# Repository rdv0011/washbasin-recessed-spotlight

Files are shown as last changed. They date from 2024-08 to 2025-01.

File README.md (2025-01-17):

# Instructions on how to replace a halogen lamp with an LED lamp in a recessed spotlight in a bathroom.

## The following parts need to be purchased

[LED 12V power supply example](https://www.wish.com/product/5b739aba85276f4d7be6cf43).

Any 12V DC power supply with a current of at least 250mA will do. The height of the power supply must accommodate the limited space inside the washbasin furniture.

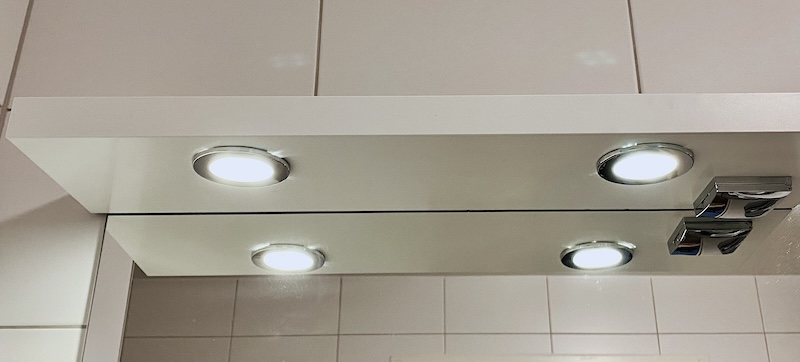
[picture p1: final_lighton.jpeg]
Final light on

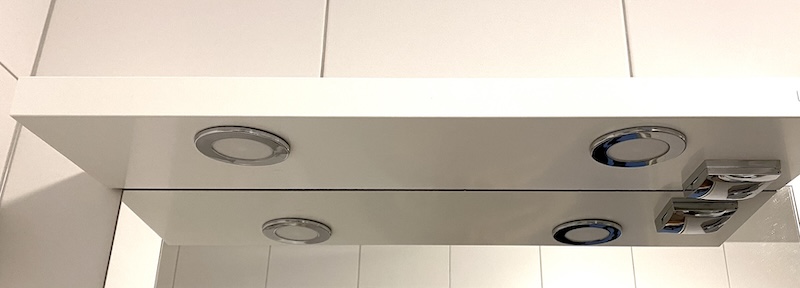
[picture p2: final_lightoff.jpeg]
Final light off


[Aluminum radiator 100x25](https://www.wish.com/search/aluminum%20radiator/product/5ae2c8115194c93728249dd5?source=search&position=48)

[3W Warm white LED](https://www.wish.com/search/LED%203W/product/5957245b2038c73845957045?source=search&position=8)
It is better to use 3W not 1W LED chip. The 3W LED has 2.9V drop wich for 4 LEDs gives 11.6V. This power supply output is 12.12v. The difference is 12.12 - 11.6 = 0.52V. If we want current to be 0.125A then resistor nominal is 0.52V / 0.125A = approx. 4 Ohm. With the current 0.125A four LEDs do not heat up more than 60C. The current limiting resistor dissipates 0.065W.

All necessary parts

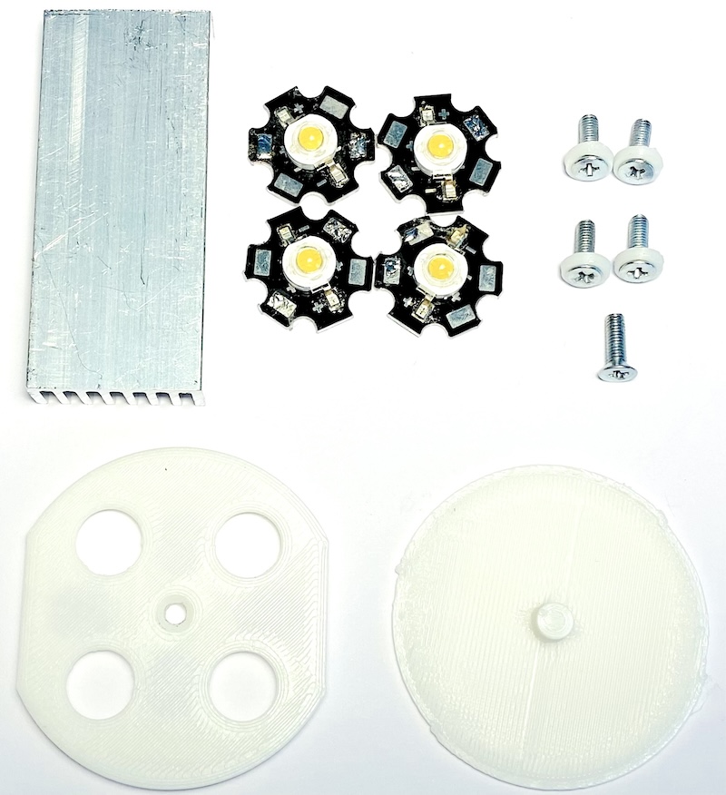
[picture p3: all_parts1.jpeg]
All parts


A wire with a 4 ohm resistor to connect to a 12V DC power supply.

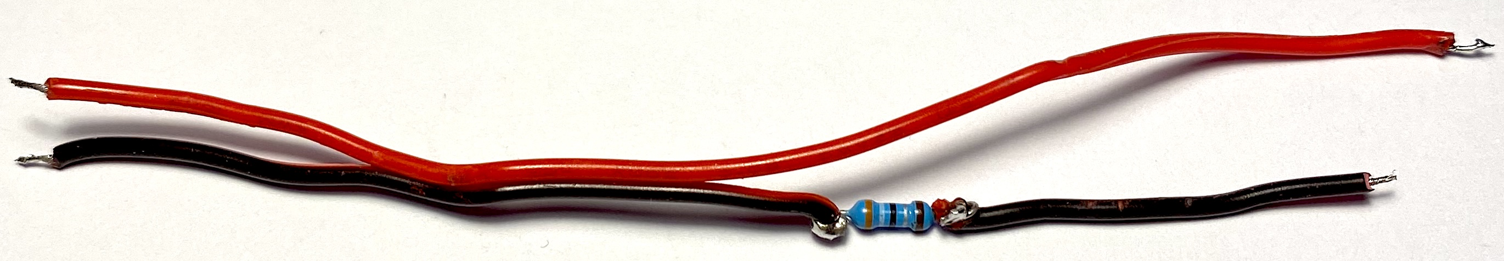
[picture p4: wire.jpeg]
Wire

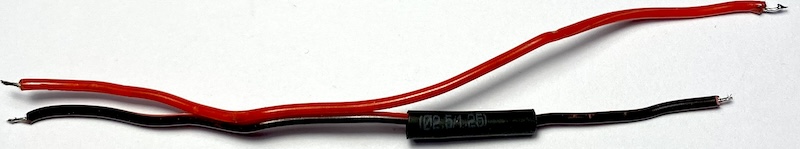
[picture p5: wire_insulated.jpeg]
Wire insulated


Take an aluminum radiator that is 25mm wide, 10mm high and 40mm long or more.

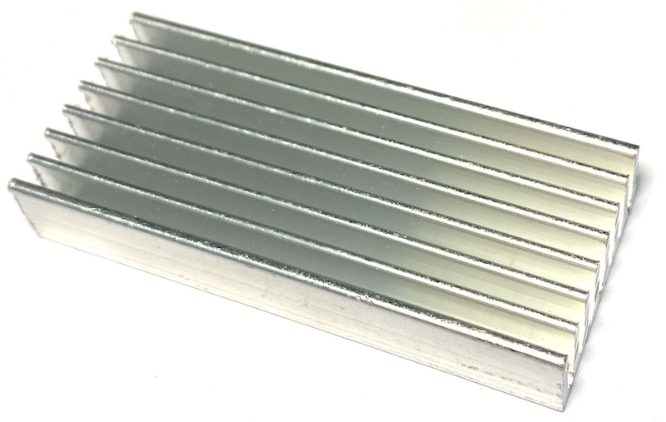
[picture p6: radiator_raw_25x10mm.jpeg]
Raw radiator


Print out the radiator template. To maintain the correct size, use a 103% scaling factor if required by your printer.

Radiator template

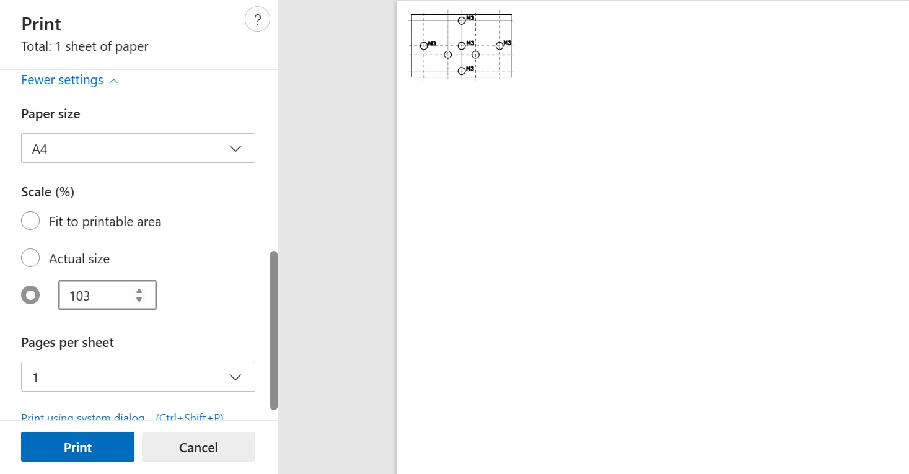
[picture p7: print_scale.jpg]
Print scale


Glue the template to the radiator blank and cut according to the template.

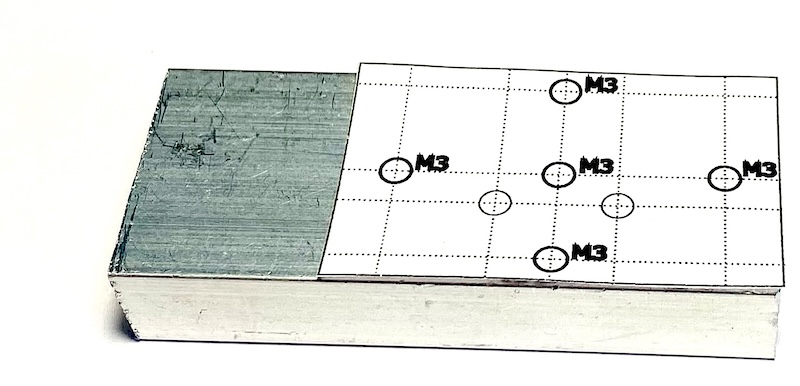
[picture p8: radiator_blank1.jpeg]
Template on radiator


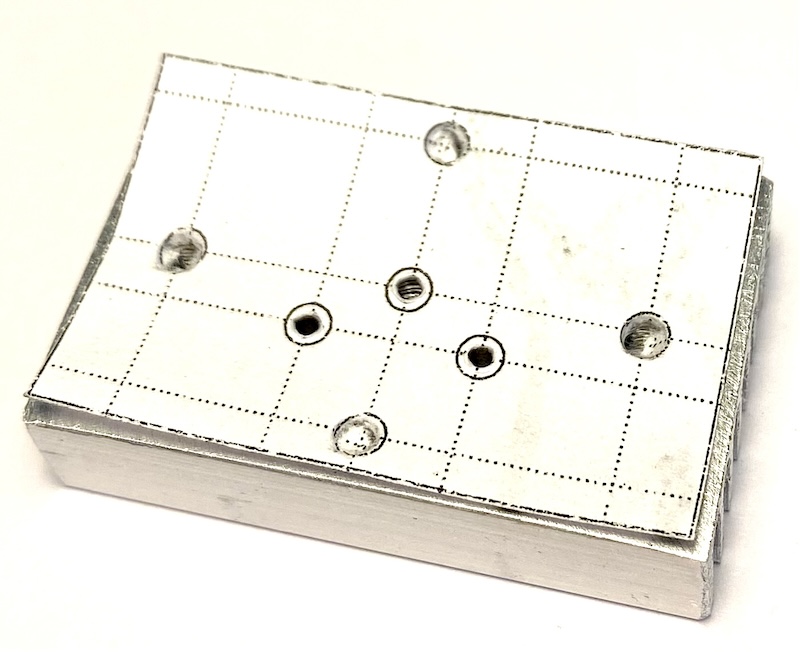
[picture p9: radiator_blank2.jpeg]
Template on radiator


Drill holes with a 2.5 mm drill marked M3. After this, make an M3 thread in the holes marked M3. Drill the remaining two holes with a diameter of 3 mm.

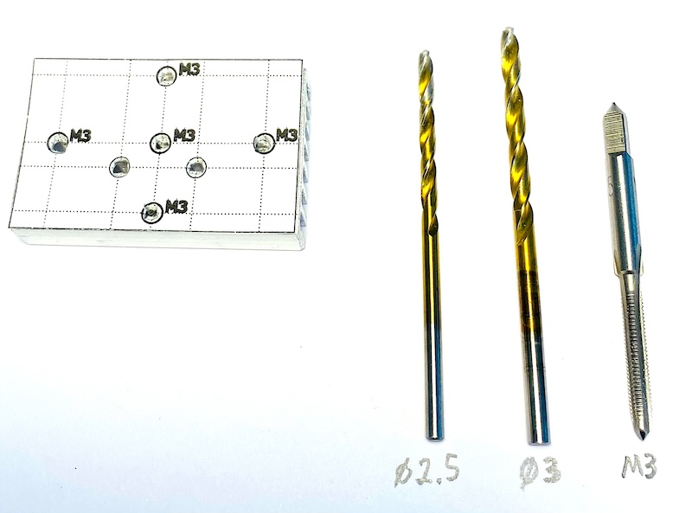
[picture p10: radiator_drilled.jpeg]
Template on radiator

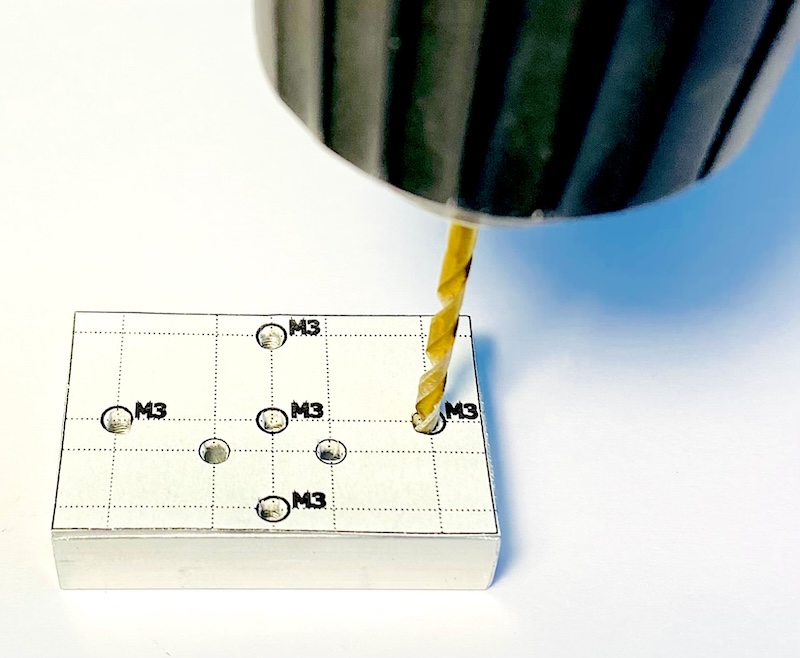
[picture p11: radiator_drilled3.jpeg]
Drilled radiator

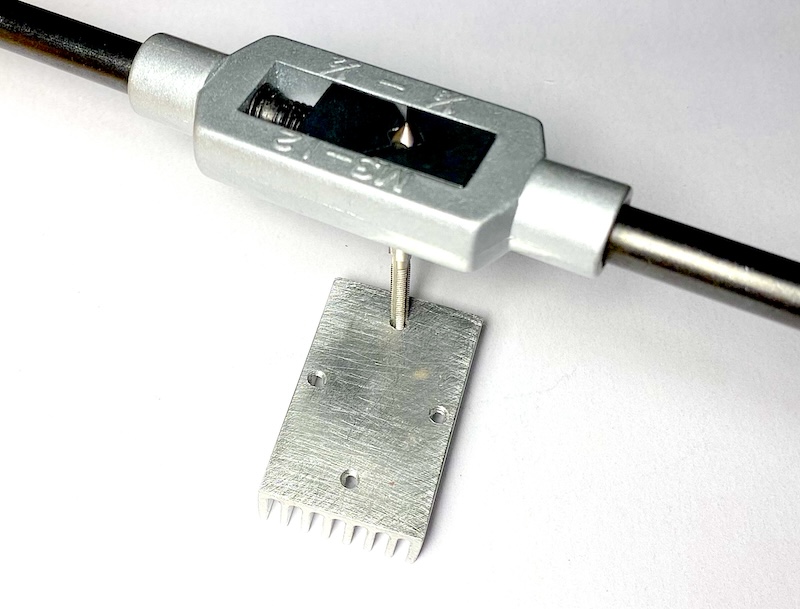
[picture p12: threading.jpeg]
Threads

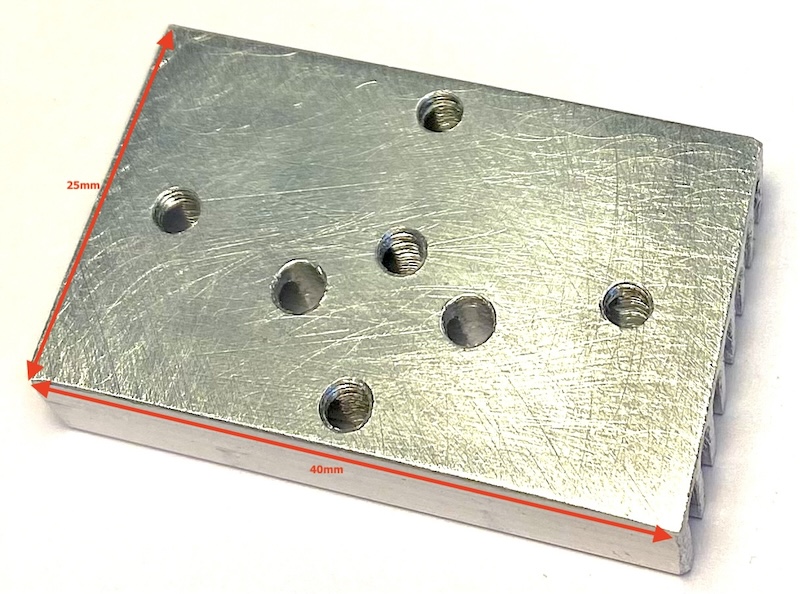
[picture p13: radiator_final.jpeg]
Final radiator


Align the 4 LED chips and solder them with flux. LEDs are easier to solder and align when they are bolted to the heatsink.

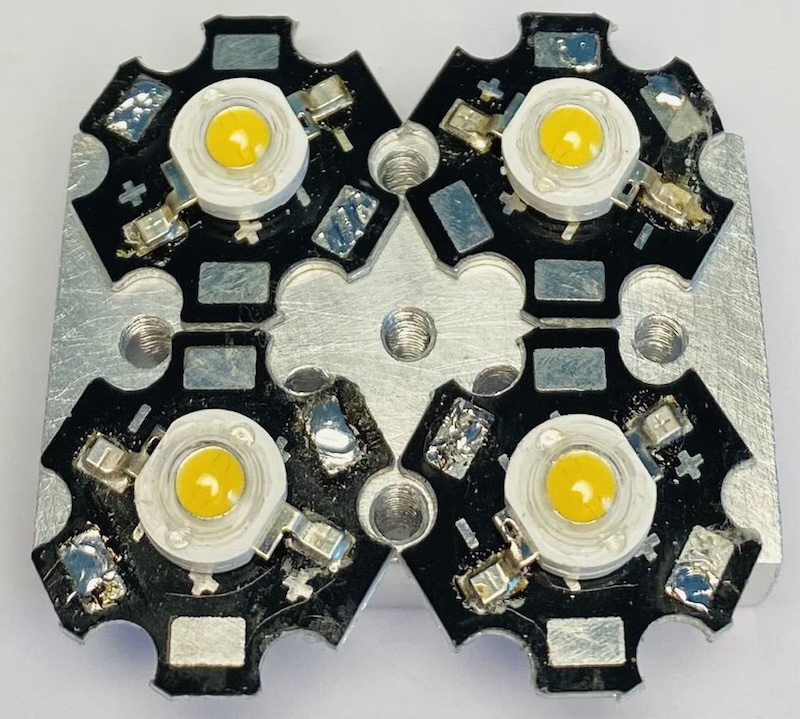
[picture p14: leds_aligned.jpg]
Align LEDS

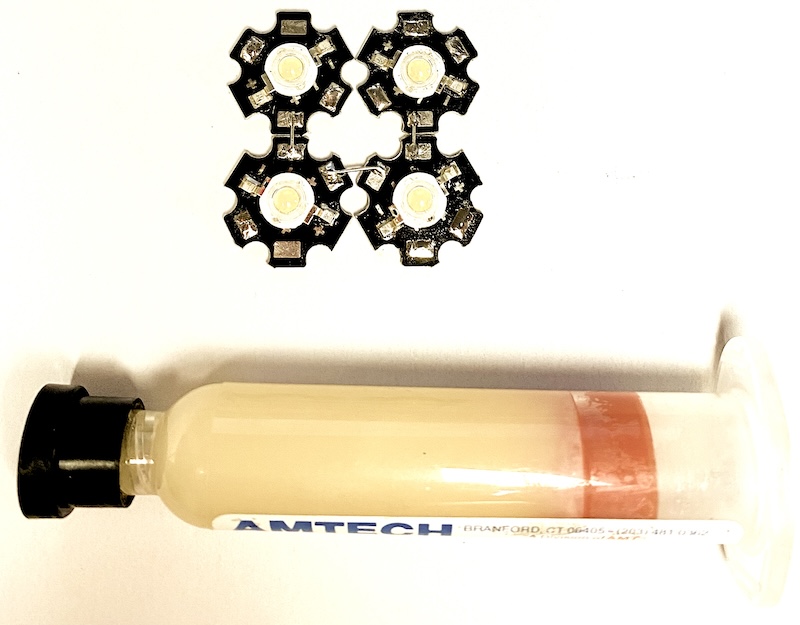
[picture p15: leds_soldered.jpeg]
Soldered LEDS


To complete the heatsink assembly, unseal the washers and use screws to secure the LEDs to the heatsink.

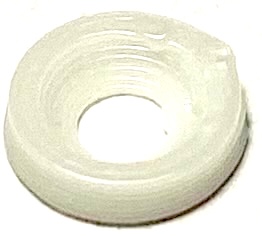
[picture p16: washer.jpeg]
Washer


[Washer STL file](light_washer.stl)

The screw diameter is 3 mm, the length is 10 mm. Five screws are needed total for one spotlight.

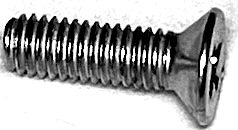
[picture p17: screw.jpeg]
Screw

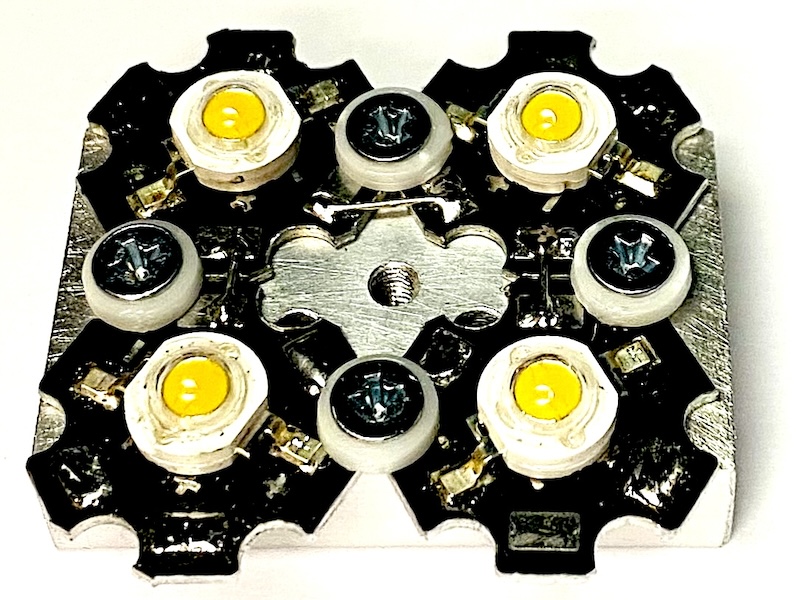
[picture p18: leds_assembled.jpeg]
LEDs assembled

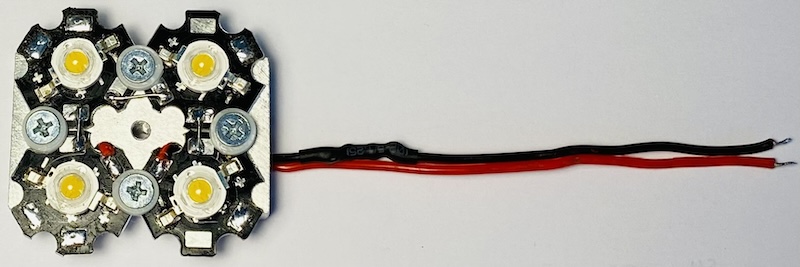
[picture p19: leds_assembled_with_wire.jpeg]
LEDs assembled with wire


Print the diffuser and reflector

[Light diffuser](light_diffuser_washbasin.stl)
[Light reflector](light_reflector_washbasin.stl)

Screw the light reflector to the radiator with an M3 screw.

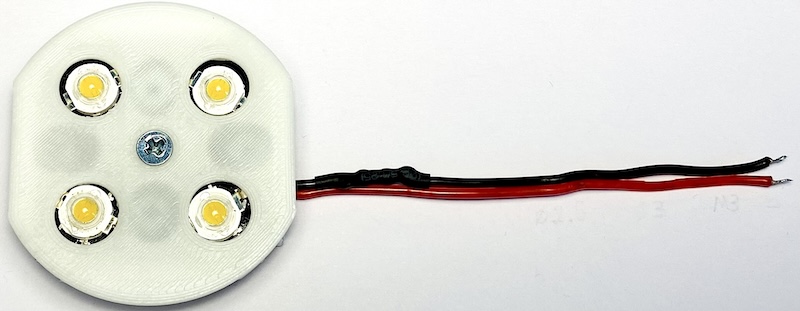
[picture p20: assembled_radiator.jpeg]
Assembled radiator


Print the information label and use double-sided tape to create an information sticker.

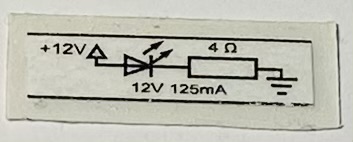
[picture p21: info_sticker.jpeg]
Info sticker


Fully assembled LED with information sticker

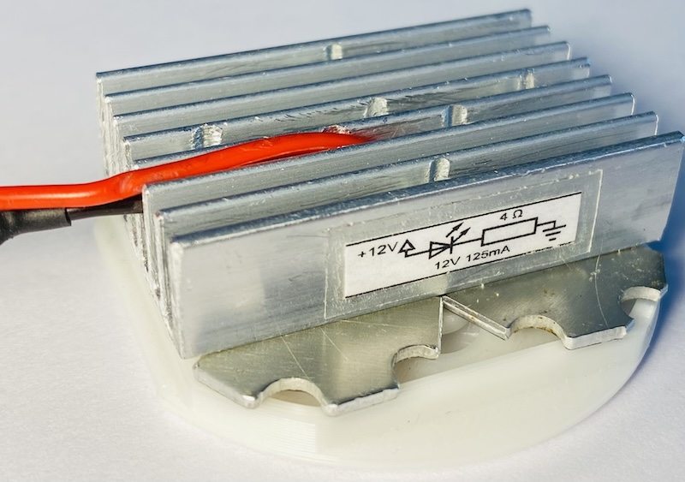
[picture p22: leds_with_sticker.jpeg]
LED with sticker


Make a hole 40x25mm in the spotlight cup

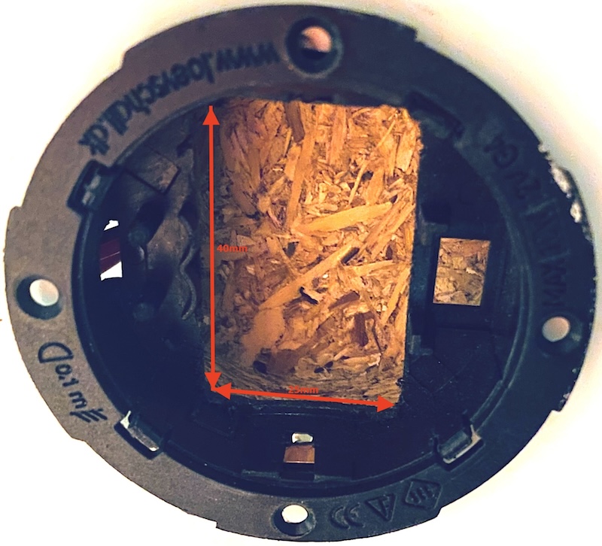
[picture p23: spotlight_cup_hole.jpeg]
Spotlight cup hole


Remove the old glass light diffuser and install the previously printed plastic light diffuser into the frame.

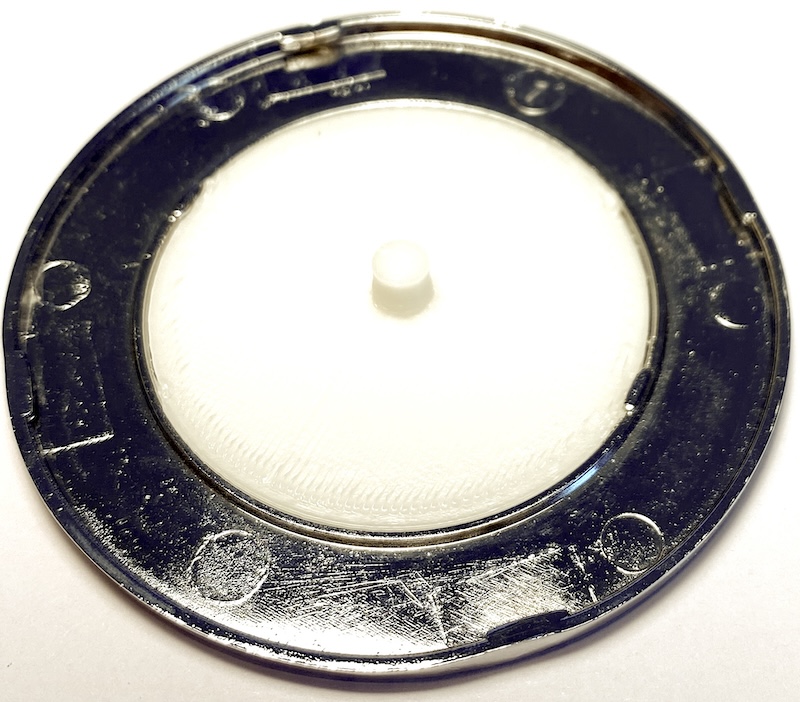
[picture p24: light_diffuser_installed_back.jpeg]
Lisght diffuser back

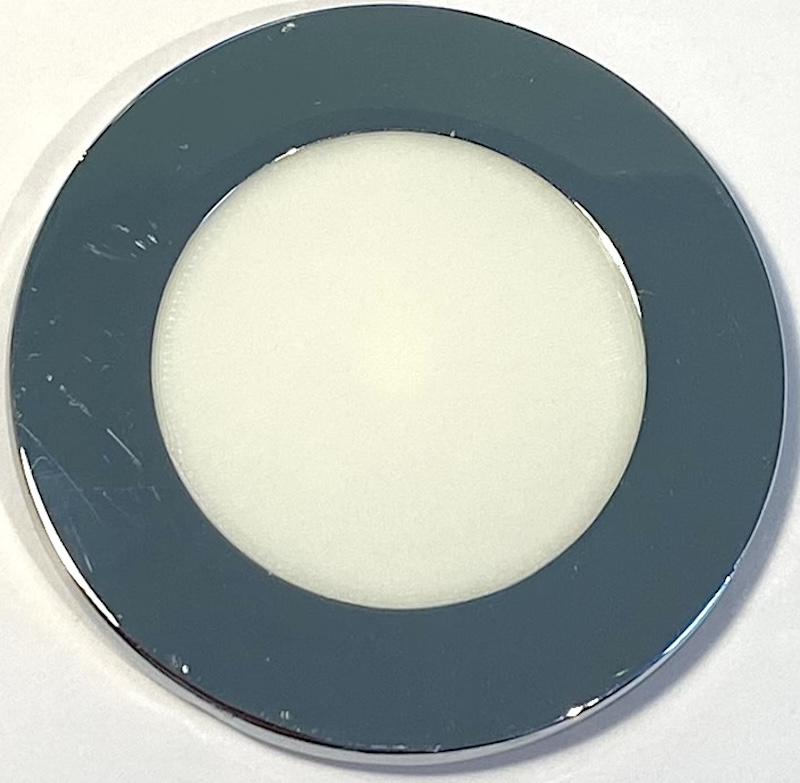
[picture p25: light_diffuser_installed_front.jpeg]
Light diffuser front


Remove the old halogen transformer and associated wires and replace it with a new 12V LED transformer in the washbasin furniture. Install the LED spotlight into the furniture and connect the wires. To connect two spotlights to one transformer, you can use a 2 to 4 splitter.
[Wrire splitter](https://www.wish.com/search/wire%20splitter/product/6412b6e2b64cc73cb05a2703?source=search&position=14)

The wire layout inside a washbasin furniture

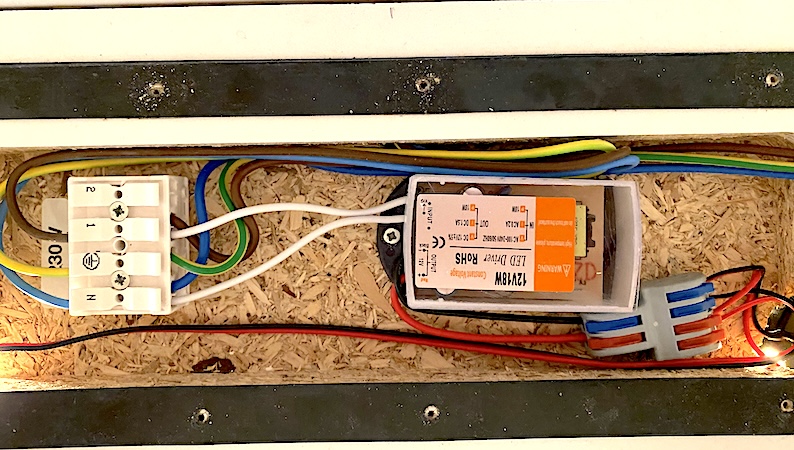
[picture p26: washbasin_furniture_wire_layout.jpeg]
Wire layout


The spotlight is installed

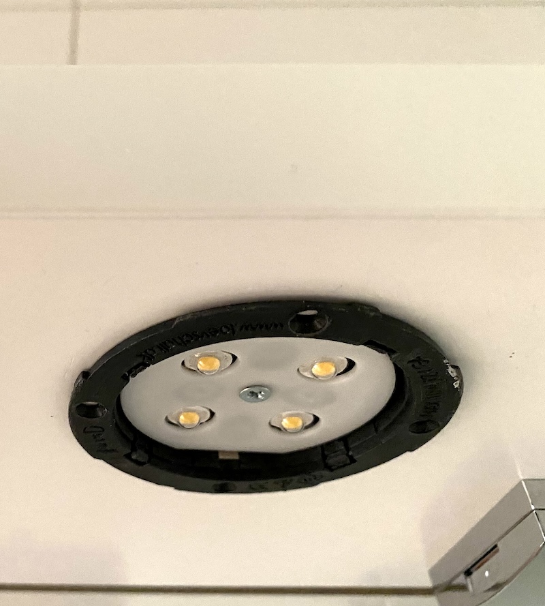
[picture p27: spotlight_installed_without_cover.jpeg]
Spotlight installed

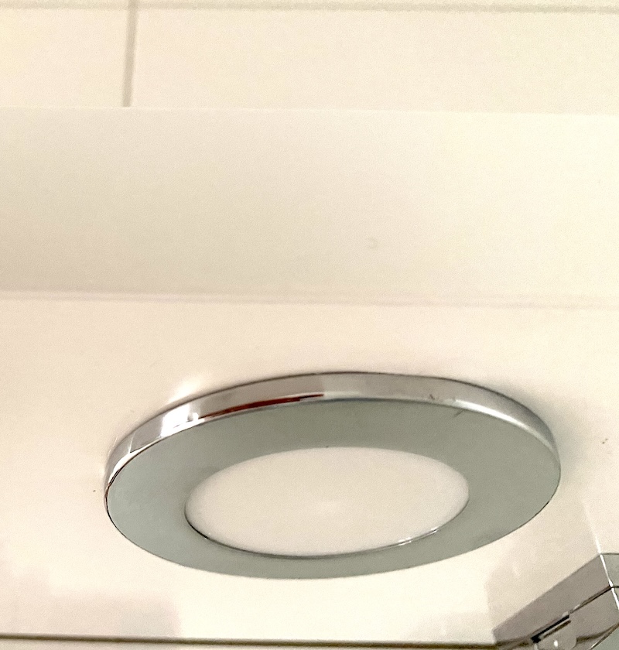
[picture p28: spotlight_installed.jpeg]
Spotlight installed


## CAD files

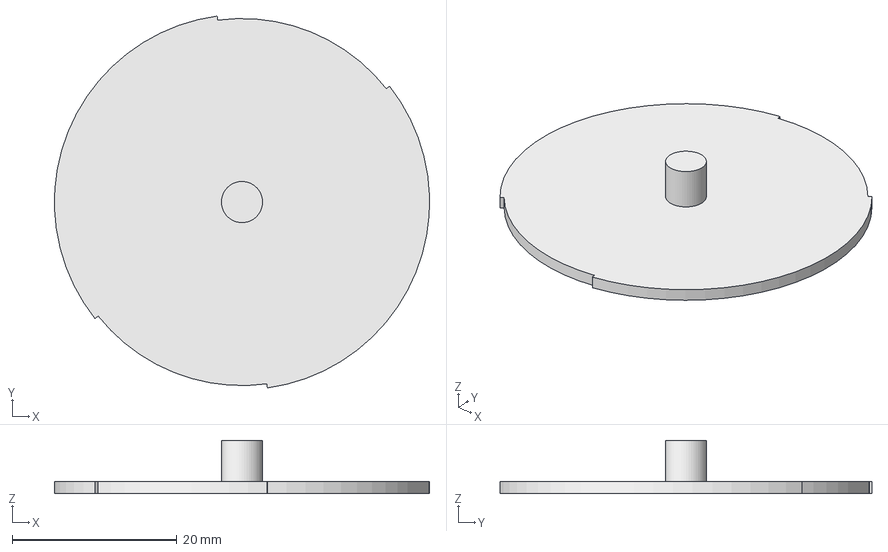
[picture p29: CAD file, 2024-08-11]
light_diffuser_washbasin.FCStd
45.6 x 45.2 x 6.50 mm

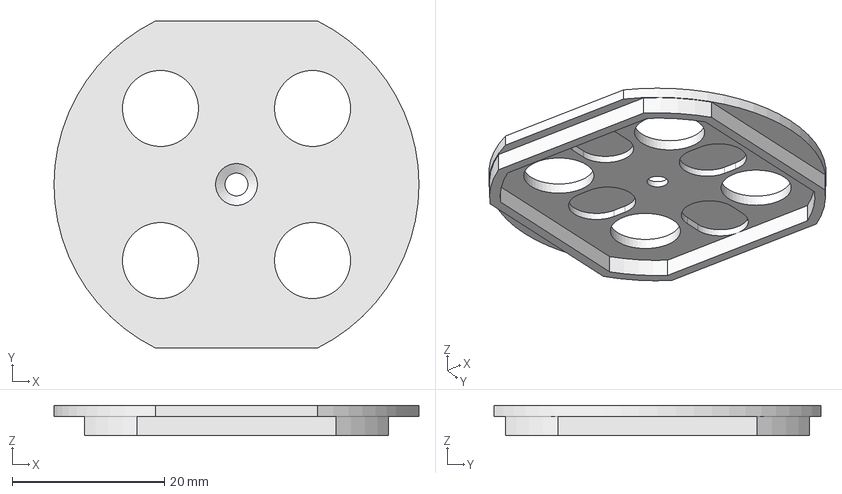
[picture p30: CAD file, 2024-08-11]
light_reflector_washbasin.FCStd
48.0 x 43.0 x 4.00 mm

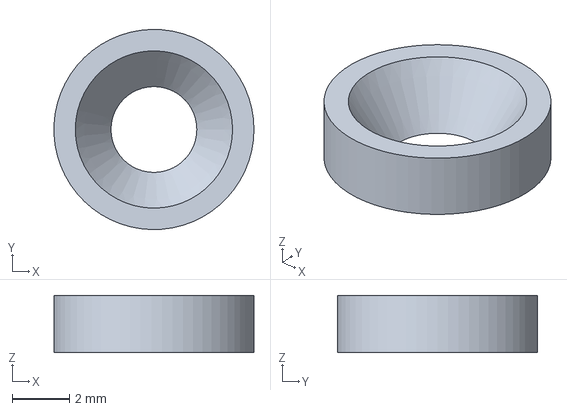
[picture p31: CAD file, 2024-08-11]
light_washer.FCStd
7.00 x 7.00 x 2.00 mm

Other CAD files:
light_diffuser_washbasin.stl
light_reflector_washbasin.stl
light_washer.stl

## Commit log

2024-08-11 Washbasin LED recessed spotlight
    [light_diffuser_washbasin.FCStd, light_diffuser_washbasin.stl, light_reflector_washbasin.FCStd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]
2025-01-17 Add information about LED voltage drop
